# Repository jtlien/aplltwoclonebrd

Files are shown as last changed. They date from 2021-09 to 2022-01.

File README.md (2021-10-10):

# aplltwoclonebrd
An apple II clone board in kicad 
I needed a good source of documentation for the Apple II clone board that I had bought back in the early 1980s.   It wat in my closet for about 40 years and I recently wanted to get it out to get it to work and could not find a good source of documentation in an up to date CAD system.   So I made this design which represents to the best of my knowledge the original apple 2 clone board that I had.
As of Fall/2021, I have a fairly complete schemtic, chip layout and the start of a routed board in KICAD.    This may also be convenient for people building or working on vintage apple II hardware to use some of the nice KICAD tools like iBom to populate their boards etc.    Plus the design rule checkers should they get to the point of building a board.   My own plans are possibly to build a four layer board, with only a +5 Volt supply (-5v can be generated by a buck converter chip).
+12 and -12 Volts were needed for old serial ports and are not used much anymore.

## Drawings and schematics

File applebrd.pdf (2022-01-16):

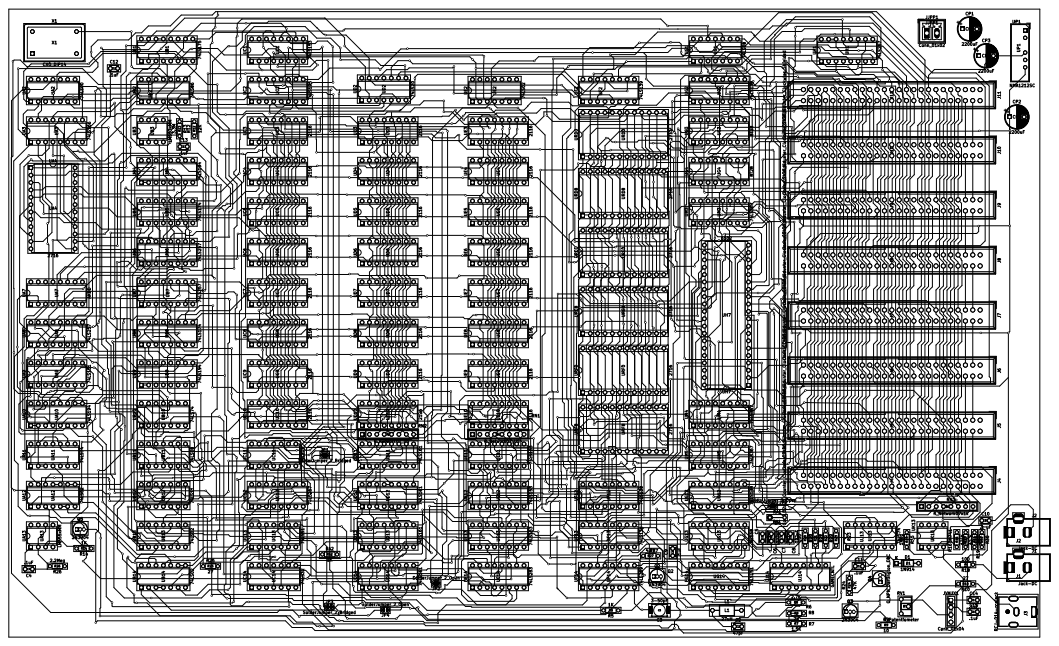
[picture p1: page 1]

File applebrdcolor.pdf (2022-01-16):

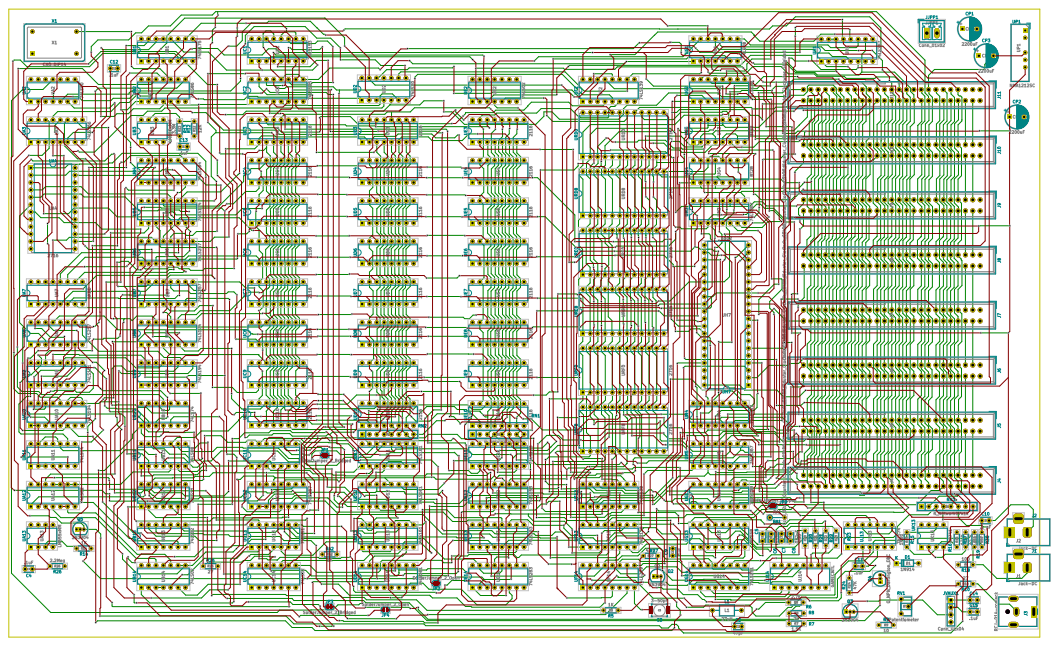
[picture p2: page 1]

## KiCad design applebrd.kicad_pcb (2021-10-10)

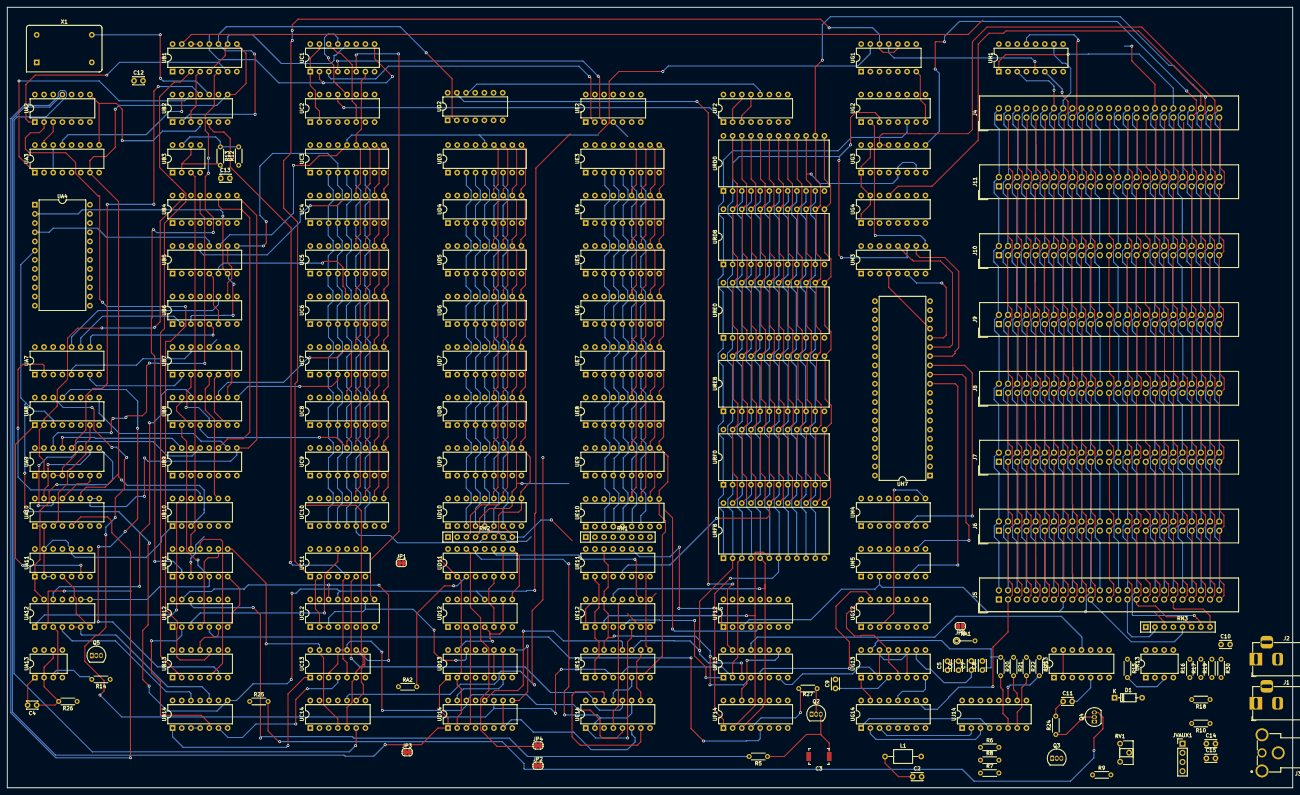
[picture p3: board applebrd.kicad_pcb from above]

Board: 4 copper layers, 355.6 x 215.9 mm, 156 parts (0 on the bottom side), 322 nets.

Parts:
C2: 47pF; C_Disc_D3.0mm_W2.0mm_P2.50mm
C3: 3-50pF; C_Trimmer_Murata_TZW4
C4, C9, C11, C12, C13, C14, C15: .1uF; C_Disc_D3.0mm_W2.0mm_P2.50mm
C5, C6, C7, C8: .022uF; C_Disc_D3.0mm_W2.0mm_P2.50mm
C10: .1 uF; C_Disc_D3.0mm_W2.0mm_P2.50mm
D1: 1N914; D_DO-35_SOD27_P7.62mm_Horizontal
J1, J2: Jack-DC; BarrelJack_Horizontal
J3: RCJ-014; CUI_RCJ-014
J4, J5, J6, J7, J8, J9, J10, J11: Conn_02x25_Counter_Clockwise_Shielded; IDC-Header_2x25_P2.54mm_Vertical
JP1, JP3: SolderJumper_2_Bridged; SolderJumper-2_P1.3mm_Bridged_RoundedPad1.0x1.5mm
JP2, JP4, JP9: SolderJumper_2_Open; SolderJumper-2_P1.3mm_Open_RoundedPad1.0x1.5mm
JVAUX1: Conn_01x04; PinHeader_1x04_P2.54mm_Vertical
L1: 27uH; L_Axial_L5.0mm_D3.6mm_P10.00mm_Horizontal_Murata_BL01RN1A2A2
Q2, Q3, Q5: 2N3904; TO-92_Inline
Q4: Q_NPN_Darlington_EBC; TO-92_Inline
R5, R14: 1K; R_Axial_DIN0204_L3.6mm_D1.6mm_P5.08mm_Horizontal
R6: 2.7K; R_Axial_DIN0204_L3.6mm_D1.6mm_P5.08mm_Horizontal
R7: 1.5K; R_Axial_DIN0204_L3.6mm_D1.6mm_P5.08mm_Horizontal
R8: 2K; R_Axial_DIN0204_L3.6mm_D1.6mm_P5.08mm_Horizontal
R9: 10; R_Axial_DIN0204_L3.6mm_D1.6mm_P5.08mm_Horizontal
R10, R25: 27; R_Axial_DIN0204_L3.6mm_D1.6mm_P5.08mm_Horizontal
R12, R19, R30: 12K; R_Axial_DIN0204_L3.6mm_D1.6mm_P5.08mm_Horizontal
R13: 3.3M; R_Axial_DIN0204_L3.6mm_D1.6mm_P5.08mm_Horizontal
R15: 1Meg; R_Axial_DIN0204_L3.6mm_D1.6mm_P5.08mm_Horizontal
R16, R17: 12 K; R_Axial_DIN0204_L3.6mm_D1.6mm_P5.08mm_Horizontal
R18, R20, R21, R22, R23: 100; R_Axial_DIN0204_L3.6mm_D1.6mm_P5.08mm_Horizontal
R24: 47K; R_Axial_DIN0204_L3.6mm_D1.6mm_P5.08mm_Horizontal
R26: 2.2Meg; R_Axial_DIN0204_L3.6mm_D1.6mm_P5.08mm_Horizontal
R27: 4.7K; R_Axial_DIN0204_L3.6mm_D1.6mm_P5.08mm_Horizontal
RA1: 1K; R_Axial_DIN0204_L3.6mm_D1.6mm_P5.08mm_Vertical
RA2: 1K; R_Axial_DIN0204_L3.6mm_D1.6mm_P5.08mm_Horizontal
RN1, RN2: R_Network07_US; R_Array_SIP8
RN3: R_Network07x1k; R_Array_SIP8
RV1: 200; Potentiometer_ACP_CA6-H2,5_Horizontal
UA2: 74LS00; DIP-14_W7.62mm
UA3: 74LS166; DIP-16_W7.62mm
UA4: 2716; DIP-24_W15.24mm
UA7: AKBD; DIP-16_W7.62mm
UA8: 74LS257; DIP-16_W7.62mm
UA9: 74LS151; DIP-16_W7.62mm
UA10: 74LS194; DIP-16_W7.62mm
UA11: 74LS74; DIP-14_W7.62mm
UA12: 74LS02; DIP-14_W7.62mm
UA13: LM555xMM; DIP-8_W7.62mm
UB1: 74LS175; DIP-16_W7.62mm
UB2: 74LS86; DIP-14_W7.62mm
UB3: LM555xMM; DIP-8_W7.62mm
UB4, UB9: 74LS194; DIP-16_W7.62mm
UB5, UB8: 74LS174; DIP-16_W7.62mm
UB6, UB7: 74LS257; DIP-16_W7.62mm
UB10: 74LS74; DIP-14_W7.62mm
UB11: 74LS08; DIP-14_W7.62mm
UB12: 74LS11; DIP-14_W7.62mm
UB13, UB14: 74LS02; DIP-14_W7.62mm
UC1: 74LS153; DIP-16_W7.62mm
UC2: 74LS195; DIP-16_W7.62mm
UC3, UC4, UC5, UC6, UC7, UC8, UC9, UC10: 2116; DIP-18_W7.62mm
UC11: 74LS04; DIP-14_W7.62mm
UC12: 74LS257; DIP-16_W7.62mm
UC13: 74LS51; DIP-14_W7.62mm
UC14: 74LS32; DIP-14_W7.62mm
UD2: 74LS20; DIP-14_W7.62mm
UD3, UD4, UD5, UD6, UD7, UD8, UD9, UD10: 2116; DIP-18_W7.62mm
UD11, UD12, UD13, UD14: 74LS161; DIP-16_W7.62mm
UE2: 74LS02; DIP-14_W7.62mm
UE3, UE4, UE5, UE6, UE7, UE8, UE9, UE10: 2116; DIP-18_W7.62mm
UE11, UE12, UE13: 74LS153; DIP-16_W7.62mm
UE14: 74LS283; DIP-16_W7.62mm
UF2: 74LS139; DIP-16_W7.62mm
UF12, UF13: 74LS138; DIP-16_W7.62mm
UF14: 74LS259; DIP-16_W7.62mm
UG1: 74LS08; DIP-14_W7.62mm
UG2, UG12: 74LS138; DIP-16_W7.62mm
UG3, UG4: 8T28; DIP-16_W7.62mm
UG13: NE558; DIP-16_W7.62mm
UG14: 74LS251; DIP-16_W7.62mm
UH1: 74LS257; DIP-16_W7.62mm
UH7: WD65C02; DIP-40_W15.24mm
UJ13: 74LS74; DIP-14_W7.62mm
UJ14: GAMECNTL; DIP-16_W7.62mm
UK13: LM741; DIP-8_W7.62mm
UM3, UM4, UM5: 74LS367; DIP-16_W7.62mm
URD0, URD8: 2716; DIP-24_W15.24mm
URE0, URE8: 2716; DIP-24_W15.24mm
URF0, URF8: 2716; DIP-24_W15.24mm
X1: CXO_DIP14; Oscillator_DIP-14

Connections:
+5V: J4.25, J5.25, J6.25, J7.25, J8.25, J9.25, J10.25, J11.25, R9.1, R12.1, R26.1, RA1.1, RA2.1, RN1.1, RN3.1, UA2.14, UA3.16, UA4.24, UA7.1, UA8.16, UA9.16, UA10.16, UA11.14, UA12.14, UA13.4, UA13.8, UB1.16, UB2.14, UB3.4, UB3.8, UB4.16, UB5.16, UB6.16, UB7.16, UB8.16, UB9.16, UB10.14, UB11.14, UB12.14, UB13.14, UB14.14, UC1.16, UC2.16, UC3.16, UC4.16, UC5.16, UC6.16, UC7.16, UC8.16, UC9.16, UC10.16, UC11.14, UC12.16, UC13.14, UC14.14, UD2.14, UD3.16, UD4.16, UD5.16, UD6.16, UD7.16, UD8.16, UD9.16, UD10.16, UD11.16, UD12.16, UD13.16, UD14.16, UE2.14, UE3.16, UE4.16, UE5.16, UE6.16, UE7.16, UE8.16, UE9.16, UE10.16, UE11.16, UE12.16, UE13.16, UE14.16, UF12.16, UF13.16, UF14.16, UG1.14, UG2.16, UG3.16, UG4.16, UG12.16, UG13.5, UG13.13, UG14.16, UJ13.14, UJ14.1, UK13.7, UM3.16, UM4.16, UM5.16, URD0.24, URD8.24, URE0.24, URE8.24, URF0.24, URF8.24, X1.1, X1.14
+12V: C14.1, J4.50, J5.50, J6.50, J7.50, J8.50, J9.50, J10.50, J11.50, JVAUX1.1
-5V: C15.1, J4.34, J5.34, J6.34, J7.34, J8.34, J9.34, J10.34, JVAUX1.2, UK13.4
-12V: J4.33, J5.33, J6.33, J7.33, J8.33, J9.33, J10.33
/7M: J4.36, J5.36, J6.36, J7.36, J8.36, J9.36, J10.36, J11.36, UB1.15, UB2.1, UB12.9
/14M: UA3.7, UA10.9, UA10.10, UA10.11, UB1.9, UB2.8, UB4.9, UB9.9, UB10.3, UB12.8, UC2.10
/A0: J4.2, J5.2, J6.2, J7.2, J8.2, J9.2, J10.2, J11.2, UE13.3, UF14.13, UG14.11, UM5.11, URD0.8, URD8.8, URE0.8, URE8.8, URF0.8, URF8.8
/A1: J4.3, J5.3, J6.3, J7.3, J8.3, J9.3, J10.3, J11.3, UE13.13, UF14.1, UG14.10, UM4.5, URD0.7, URD8.7, URE0.7, URE8.7, URF0.7, URF8.7
/A2: J4.4, J5.4, J6.4, J7.4, J8.4, J9.4, J10.4, J11.4, UE12.3, UF14.2, UG14.9, UM5.7, URD0.6, URD8.6, URE0.6, URE8.6, URF0.6, URF8.6
/A3: J4.5, J5.5, J6.5, J7.5, J8.5, J9.5, J10.5, J11.5, UE12.13, UF14.3, UM5.9, URD0.5, URD8.5, URE0.5, URE8.5, URF0.5, URF8.5
/A4: J4.6, J5.6, J6.6, J7.6, J8.6, J9.6, J10.6, J11.6, UE12.5, UF13.1, UG2.1, UM4.7, URD0.4, URD8.4, URE0.4, URE8.4, URF0.4, URF8.4
/A5: J4.7, J5.7, J6.7, J7.7, J8.7, J9.7, J10.7, J11.7, UE13.5, UF13.2, UG2.2, UM3.9, URD0.3, URD8.3, URE0.3, URE8.3, URF0.3, URF8.3
/A6: J4.8, J5.8, J6.8, J7.8, J8.8, J9.8, J10.8, J11.8, UE13.11, UF13.3, UG2.3, UM3.11, URD0.2, URD8.2, URE0.2, URE8.2, URF0.2, URF8.2
/A7: J4.9, J5.9, J6.9, J7.9, J8.9, J9.9, J10.9, J11.9, UE11.3, UF13.6, UG2.6, UM3.7, URD0.1, URD8.1, URE0.1, URE8.1, URF0.1, URF8.1
/A8: J4.10, J5.10, J6.10, J7.10, J8.10, J9.10, J10.10, J11.10, UE11.13, UG12.1, UM3.5, URD0.23, URD8.23, URE0.23, URE8.23, URF0.23, URF8.23
/A9: J4.11, J5.11, J6.11, J7.11, J8.11, J9.11, J10.11, J11.11, UE12.11, UG12.2, UM3.3, URD0.22, URD8.22, URE0.22, URE8.22, URF0.22, URF8.22
/A10: J4.12, J5.12, J6.12, J7.12, J8.12, J9.12, J10.12, J11.12, UE11.5, UG12.3, UM4.9, URD0.19, URD8.19, URE0.19, URE8.19, URF0.19, URF8.19
/A11: J4.13, J5.13, J6.13, J7.13, J8.13, J9.13, J10.13, J11.13, UE11.11, UF12.1, UM4.11
/A12: J4.14, J5.14, J6.14, J7.14, J8.14, J9.14, J10.14, J11.14, UC1.3, UE2.2, UF12.2, UH1.3, UM4.3
/A12-13: UA9.9, UA11.1, UA12.13
/A13: J4.15, J5.15, J6.15, J7.15, J8.15, J9.15, J10.15, J11.15, UC1.4, UE2.3, UF12.3, UH1.6, UM5.3
/A14: J4.16, J5.16, J6.16, J7.16, J8.16, J9.16, J10.16, J11.16, UG1.4, UH1.10, UM5.13
/A15: J4.17, J5.17, J6.17, J7.17, J8.17, J9.17, J10.17, J11.17, UG1.5, UH1.13, UM4.13
/AD0: UH7.9, UM5.12
/AD1: UH7.10, UM4.4
/AD2: UH7.11, UM5.6
/AD3: UH7.12, UM5.10
/AD4: UH7.13, UM4.6
/AD5: UH7.14, UM3.10
/AD6: UH7.15, UM3.12
/AD7: UH7.16, UM3.6
/AD8: UH7.17, UM3.4
/AD9: UH7.18, UM3.2
/AD10: UH7.19, UM4.10
/AD11: UH7.20, UM4.12
/AD12: UH7.22, UM4.2
/AD13: UH7.23, UM5.2
/AD14: UH7.24, UM5.14
/AD15: UH7.25, UM4.14
/AN0: UF14.9, UJ14.15
/AN1: UF14.10, UJ14.14
/AN2: UF14.11, UJ14.13
/AN3: UF14.12, UJ14.12
/AX: UB13.9, UC1.14, UC2.4, UC2.6, UC2.14, UE11.2, UE12.2, UE13.2
/CASSETTE_OUT: UF13.13, UJ13.11
/CREF: UB1.3, UB13.2
/D0: J4.49, J5.49, J6.49, J7.49, J8.49, J9.49, J10.49, J11.49, UG4.2, UG4.4, URD0.9, URD8.9, URE0.9, URE8.9, URF0.9, URF8.9
/D1: J4.48, J5.48, J6.48, J7.48, J8.48, J9.48, J10.48, J11.48, UG3.2, UG3.4, URD0.10, URD8.10, URE0.10, URE8.10, URF0.10, URF8.10
/D2: J4.47, J5.47, J6.47, J7.47, J8.47, J9.47, J10.47, J11.47, UG3.13, UG3.14, URD0.11, URD8.11, URE0.11, URE8.11, URF0.11, URF8.11
/D3: J4.46, J5.46, J6.46, J7.46, J8.46, J9.46, J10.46, J11.46, UG4.13, UG4.14, URD0.13, URD8.13, URE0.13, URE8.13, URF0.13, URF8.13
/D4: J4.45, J5.45, J6.45, J7.45, J8.45, J9.45, J10.45, J11.45, UG4.5, UG4.7, URD0.14, URD8.14, URE0.14, URE8.14, URF0.14, URF8.14
/D5: J4.44, J5.44, J6.44, J7.44, J8.44, J9.44, J10.44, J11.44, UG3.5, UG3.7, URD0.15, URD8.15, URE0.15, URE8.15, URF0.15, URF8.15
/D6: J4.43, J5.43, J6.43, J7.43, J8.43, J9.43, J10.43, J11.43, UG3.9, UG3.11, URD0.16, URD8.16, URE0.16, URE8.16, URF0.16, URF8.16
/D7: J4.42, J5.42, J6.42, J7.42, J8.42, J9.42, J10.42, J11.42, UA8.13, UG4.9, UG4.11, UG14.5, URD0.17, URD8.17, URE0.17, URE8.17, URF0.17, URF8.17
/DB0: UB6.9, UG4.3, UH7.33
/DB1: UB6.12, UG3.3, UH7.32
/DB2: UB6.7, UH7.31
/DB3: UB6.4, UH7.30
/DB4: UB7.9, UG4.6, UH7.29
/DB5: UB7.12, UG3.6, UH7.28
/DB6: UB7.4, UG3.10, UH7.27
/DB7: UB7.7, UG4.10, UH7.26
/DEV_SEL_0: J4.41, UG2.15
/DEV_SEL_1: J5.41, UG2.14
/DEV_SEL_2: J6.41, UG2.13
/DEV_SEL_3: J7.41, UG2.12
/DEV_SEL_4: J8.41, UG2.11
/DEV_SEL_5: J9.41, UG2.10
/DEV_SEL_6: J10.41, UG2.9
/DEV_SEL_7: J11.41, UG2.7
/DMAIN1: J4.24, J5.27
/DMAIN2: J5.24, J6.27
/DMAIN3: J6.24, J7.27
/DMAIN4: J7.24, J8.27
/DMAIN5: J8.24, J9.27
/DMAIN6: J9.24, J10.27
/DMAIN7: J10.24, J11.27
/F13_7: UF13.7, UG13.3, UG13.6, UG13.11, UG13.14
/GRAPHICS_TXT: R27.2, UB13.12, UF14.4
/H0: UA8.14, UC13.10, UC13.11, UD14.14, UE13.4
/H1: UB13.3, UD14.13, UE13.12
/H2: UD14.12, UE12.4
/H3: UB12.2, UC13.3, UD14.11, UE14.5
/H4: UB14.5, UC13.2, UD13.14, UE14.3
/H5: UB14.6, UC11.5, UC13.4, UC13.5, UD13.13
/HBL: UB12.13, UC12.14, UC13.6, UC13.9, UC14.5
/HIRES: UB11.6, UC11.1, UC12.5, UG1.10, UG1.12
/INTIN1: J4.23, J5.28
/INTIN2: J5.23, J6.28
/INTIN3: J6.23, J7.28
/INTIN4: J7.23, J8.28
/INTIN5: J8.23, J9.28
/INTIN6: J9.23, J10.28
/INTIN7: J10.23, J11.28
/IO_SEL_1: J4.18, J5.1, J5.18, J6.18, J7.18, J8.18, J9.18, J10.18, J11.18, UA2.4, UG12.14
/IO_SEL_2: J6.1, UG12.13
/IO_SEL_3: J7.1, UG12.12
/IO_SEL_4: J8.1, UG12.11
/IO_SEL_5: J9.1, UG12.10
/IO_SEL_6: J10.1, UG12.9
/IO_SEL_7: J11.1, UG12.7
/K6: UA7.7, UB7.2
/KB0: UA7.12, UB6.11
/KB1: UA7.13, UB6.14
/KB2: UA7.10, UB6.5
/KB3: UA7.11, UB6.2
/KB4: UA7.6, UB7.11
/KB5: UA7.5, UB7.14
/KB7: UB7.5, UB10.9
/LORES_HIRES: UB11.4, UF14.7
/MIX_MODE: UB12.5, UF14.5
/P0: J4.38, J4.40, J5.38, J5.40, J6.38, J6.40, J7.38, J7.40, J8.38, J8.40, J9.38, J9.40, J10.38, J10.40, J11.38, J11.40, UA2.1, UB1.6, UB1.7, UB11.2, UB12.10, UD2.5, UE11.14, UE12.14, UE13.14, UF12.4, UF13.4, UG2.5, UH1.1
/Q3: J4.37, J5.37, J6.37, J7.37, J8.37, J9.37, J10.37, J11.37, UC1.13, UC2.9, UC2.12
/R5: C2.1, C3.1, L1.1, Q2.3, R5.1, R6.2
/RA0: RN1.7, RN2.6, UC3.10, UC4.10, UC5.10, UC6.10, UC7.10, UC8.10, UC9.10, UC10.10, UD3.10, UD4.10, UD5.10, UD6.10, UD7.10, UD8.10, UD9.10, UD10.10, UE3.10, UE4.10, UE5.10, UE6.10, UE7.10, UE8.10, UE9.10, UE10.10, UE13.7
/RA1: RN1.5, RN2.4, UC3.11, UC4.11, UC5.11, UC6.11, UC7.11, UC8.11, UC9.11, UC10.11, UD3.11, UD4.11, UD5.11, UD6.11, UD7.11, UD8.11, UD9.11, UD10.11, UE3.11, UE4.11, UE5.11, UE6.11, UE7.11, UE8.11, UE9.11, UE10.11, UE12.7
/RA2: RN1.3, RN2.3, UC3.12, UC4.12, UC5.12, UC6.12, UC7.12, UC8.12, UC9.12, UC10.12, UD3.12, UD4.12, UD5.12, UD6.12, UD7.12, UD8.12, UD9.12, UD10.12, UE3.12, UE4.12, UE5.12, UE6.12, UE7.12, UE8.12, UE9.12, UE10.12, UE11.7
/RA3: RN1.8, RN2.8, UC3.7, UC4.7, UC5.7, UC6.7, UC7.7, UC8.7, UC9.7, UC10.7, UD3.7, UD4.7, UD5.7, UD6.7, UD7.7, UD8.7, UD9.7, UD10.7, UE3.7, UE4.7, UE5.7, UE6.7, UE7.7, UE8.7, UE9.7, UE10.7, UE13.9
/RA4: RN1.6, RN2.5, UC3.6, UC4.6, UC5.6, UC6.6, UC7.6, UC8.6, UC9.6, UC10.6, UD3.6, UD4.6, UD5.6, UD6.6, UD7.6, UD8.6, UD9.6, UD10.6, UE3.6, UE4.6, UE5.6, UE6.6, UE7.6, UE8.6, UE9.6, UE10.6, UE12.9
/RA5: RN1.4, RN2.7, UC3.5, UC4.5, UC5.5, UC6.5, UC7.5, UC8.5, UC9.5, UC10.5, UD3.5, UD4.5, UD5.5, UD6.5, UD7.5, UD8.5, UD9.5, UD10.5, UE3.5, UE4.5, UE5.5, UE6.5, UE7.5, UE8.5, UE9.5, UE10.5, UE11.9
/RA6: UC1.7, UC3.13, UC4.13, UC5.13, UC6.13, UC7.13, UC8.13, UC9.13, UC10.13, UD3.13, UD4.13, UD5.13, UD6.13, UD7.13, UD8.13, UD9.13, UD10.13, UE3.13, UE4.13, UE5.13, UE6.13, UE7.13, UE8.13, UE9.13, UE10.13
/RAM_SEL: UA2.6, UB6.15, UB7.15
/RDL0: UA4.5, UB5.10, UB6.10
/RDL1: UA4.4, UB5.12, UB6.13
/RDL2: UA4.3, UB5.5, UB6.6
/RDL3: UA4.2, UB5.7, UB6.3
/RDL4: UA4.1, UB7.10, UB8.10
/RDL5: UA4.23, UB7.13, UB8.12
/RDL6: UB7.3, UB8.5, UB11.13
/RDL7: UB7.6, UB8.7, UB13.6
/RDO0: UB5.11, UC3.14, UD3.14, UE3.14
/RDO1: UB5.13, UC4.14, UD4.14, UE4.14
/RDO2: UB5.4, UC5.14, UD5.14, UE5.14
/RDO3: UB5.6, UC6.14, UD6.14, UE6.14
/RDO4: UB8.11, UC7.14, UD7.14, UE7.14
/RDO5: UB8.13, UC8.14, UD8.14, UE8.14
/RDO6: UB8.4, UC9.14, UD9.14, UE9.14
/RDO7: UB8.6, UC10.14, UD10.14, UE10.14
/RDY: J4.21, J5.21, J6.21, J7.21, J8.21, J9.21, J10.21, J11.21, RN3.5, UH7.2
/RD_KBD: UB6.1, UB7.1, UD2.13, UF13.15
/RST_KBD_STROBE: UC11.3, UF13.14
/RW: UC3.3, UC14.9, UD3.3, UE3.3, UM5.5
/SERIAL_IN: UF13.9, UG14.7
/SOFT5_11: UA2.11, UD11.1, UD12.1, UD13.1, UD13.5, UD14.1, UD14.7, UD14.10, UE14.6
/SOFT-5: UA2.8, UA3.9, UA10.1, UA10.2, UA11.2, UA11.3, UA11.10, UA11.13, UB2.4, UB5.1, UB8.1, UB10.1, UB10.4, UC2.1, UF13.12, UF14.15, UJ13.3, UJ13.4
/STROBE: UF13.11, UJ14.5
/SYNC: R8.2, UC13.8
/SYSCLK: UB2.10, X1.8
/USER1: J4.39, J5.39, J6.39, J7.39, J8.39, J9.39, J10.39, J11.39, JP9.1, RN3.8
/V0: UA4.6, UA8.3, UB14.8, UB14.9, UC12.13, UD12.12, UD12.13, UE11.4, UG1.13
/V1: JP2.1, UA4.7, UC12.6, UD12.11, UD12.14, UE11.12
/V2: JP1.1, UB12.3, UC11.11, UD11.14, UE12.10
/V3: UB11.9, UD11.13, UE14.7, UE14.14
/V4: UB11.10, UB12.4, UD11.12, UE14.2, UE14.11
/V5: JP4.1, UD11.11
/VA: UA4.8, UC11.2, UC12.2, UC12.3, UC12.10, UD13.6, UD13.11
/~7M: UA3.6, UA8.10, UB1.13, UB1.14
/~CAS: UB13.8, UC2.13, UF2.1
/~CREF: UB1.2, UB2.2, UD2.2
/~DMA: J4.22, J5.22, J6.22, J7.22, J8.22, J9.22, J10.22, J11.22, RN3.3, UB11.1, UC11.13
/~HPE: UB2.5, UD13.9, UD13.12, UD14.9
/~INH: J4.32, J5.32, J6.32, J7.32, J8.32, J9.32, J10.32, RN3.7, UE2.5, URD0.18, URD8.18, URE0.18, URE8.18, URF0.18, URF8.18
/~IOENBBL: UF12.15, UG12.4, UG12.5
/~IO_STROBE: J4.20, J5.20, J6.20, J7.20, J8.20, J9.20, J10.20, J11.20, UF12.14
/~IRQ: J4.30, J5.30, J6.30, J7.30, J8.30, J9.30, J10.30, RN3.4, UH7.4
/~LDPS: UA2.3, UA3.15, UD11.2, UD12.2, UD13.2, UD14.2
/~NMI: J4.29, J5.29, J6.29, J7.29, J8.29, J9.29, J10.29, RN3.2, UH7.6
/~RAS: UC2.7, UC2.15
/~RES: J4.31, J5.31, J6.31, J7.31, J8.31, J9.31, J10.31, Q5.3, RN3.6, UA7.3, UH7.40
GND: C2.2, C3.2, C4.2, C5.2, C6.2, C7.2, C8.2, C9.2, C12.2, C13.2, C14.2, C15.2, D1.2, J1.1, J2.1, J3.1A, J3.1B, J3.1C, J4.26, J5.26, J6.26, J7.26, J8.26, J9.26, J10.26, J11.26, JVAUX1.4, L1.2, Q2.1, Q4.1, Q5.1, R16.2, R17.2, R18.2, RN2.1, RV1.3, UA2.7, UA2.9, UA2.10, UA2.12, UA2.13, UA3.8, UA4.12, UA4.18, UA4.19, UA4.20, UA4.21, UA4.22, UA7.8, UA8.8, UA8.15, UA9.8, UA10.8, UA11.4, UA12.7, UA13.1, UB1.8, UB2.7, UB2.9, UB3.1, UB4.8, UB5.8, UB6.8, UB7.8, UB8.8, UB9.8, UB10.7, UB11.7, UB12.7, UB13.7, UB14.7, UC1.1, UC1.8, UC1.15, UC2.2, UC2.3, UC2.8, UC3.8, UC4.8, UC5.8, UC6.8, UC7.8, UC8.8, UC9.8, UC10.8, UC11.7, UC11.8, UC12.8, UC12.11, UC12.15, UC13.7, UC14.7, UD2.7, UD3.8, UD4.8, UD5.8, UD6.8, UD7.8, UD8.8, UD9.8, UD10.8, UD11.6, UD11.8, UD12.3, UD12.4, UD12.6, UD12.8, UD13.3, UD13.4, UD13.8, UD14.3, UD14.4, UD14.5, UD14.6, UD14.8, UE2.7, UE3.8, UE4.8, UE5.8, UE6.8, UE7.8, UE8.8, UE9.8, UE10.8, UE11.1, UE11.8, UE11.15, UE12.1, UE12.8, UE12.15, UE13.1, UE13.8, UE13.15, UE14.8, UF2.8, UF2.15, UF12.8, UF13.8, UF14.8, UG1.7, UG2.8, UG3.8, UG4.8, UG12.8, UG13.12, UG14.8, UH1.8, UH1.14, UH1.15, UH7.1, UH7.21, UH7.38, UJ13.7, UJ14.8, UM3.8, UM4.8, UM5.8, URD0.12, URD8.12, URE0.12, URE8.12, URF0.12, URF8.12, X1.7
unnamed: C4.1, R26.2, UA13.2, UA13.6
unnamed: C5.1, R21.1, UG13.2
unnamed: C6.1, R22.1, UG13.7
unnamed: C7.1, R23.1, UG13.10
unnamed: C8.1, R20.1, UG13.15
unnamed: C9.1, UG13.4
unnamed: C10.1, R30.1
unnamed: C10.2, J2.2
unnamed: C11.1, D1.1, R24.2
unnamed: C11.2, UJ13.5
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

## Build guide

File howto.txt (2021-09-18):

How to get the position file:
   Go to all parts on the board.   Properties.
    Change from Thru Hole to Surface mount.
    Go to Production Files: Generate .pro file.
    Quit out of board and do not save.

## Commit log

2021-10-10 Add files via upload
    Ram chp wiring fixed.
    [applebrd.kicad_pcb, applebrd.sch]
2021-12-04 Fixed packages for ram chips from 18 to 16 pin
2022-01-16 Add files via upload
    Routed board gerbers.
    [applebrd-B_Cu.gbr, applebrd-B_Mask.gbr, applebrd-B_Paste.gbr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]

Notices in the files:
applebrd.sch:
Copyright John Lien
